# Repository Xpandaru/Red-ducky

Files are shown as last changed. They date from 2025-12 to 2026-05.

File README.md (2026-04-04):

# Red-ducky

render_2 In this project I'll make my own Rubber Ducky, named Red ducky ! A Rubber Ducky is a hacking tool that mimics a keyboard to inject a sequence of keys. I started this project with no knowledge of PCB design, so it promises to be very educational.

## The story of the project

It all started when a friend introduced me to [Hack Club](https://hackclub.com/) during the [Cyber Ninja CTF](https://www.cyber-ninja-ctf.fr/) (a cybersecurity competition organized by [Oteria Cyber School](https://www.oteria.fr/)). I was quickly drawn to the [Blueprint program](https://blueprint.hackclub.com) because I knew absolutely nothing about electronics, and being very curious, I saw it as the perfect opportunity to explore the field. I soon had the idea to recreate a Rubber Ducky (a very popular cybersecurity tool) to understand how it worked and have my own by the end of the project. From there, I began learning all the necessary knowledge and developing my project based on the [custom devboard](https://blueprint.hackclub.com/starter-projects/devboard) guided project.

## Some screenshots

rendu_1

### The PCB :



### The schematic :



# How to build

## Ordering the PCB from JLCPCB

[JLCPCB](https://jlcpcb.com/) is a company that offers fast and affordable PCB manufacturing and assembly services through an easy-to-use online platform.

First, go to the [JLCPCB](https://jlcpcb.com/) website and start a new order by clicking the “Order Now” button in the top-right corner. Then, upload the [PRODUCTION.zip](https://github.com/Xpandaru/Red-ducky/blob/main/PCB/PRODUCTION/PRODUCTION.zip) file in the “Add Gerber File” field. You don’t need to change any settings except “PCB Qty” to select how many Red-Ducky boards you want. At the very bottom, enable “PCB Assembly”; again, you don’t need to change any settings. Finally, click “Next” on the right side of the screen under “Calculated Price.” Once that’s done, click “Next” again to reach the “Bill of Materials” tab, and upload the [BOM.csv](https://github.com/Xpandaru/Red-ducky/blob/main/PCB/PRODUCTION/BOM.csv) and [CPL.csv](https://github.com/Xpandaru/Red-ducky/blob/main/PCB/PRODUCTION/CPL.csv) files available in the repository.

Then click “Process BOM & CPL”, and you will see the list of components appear. However, you will likely notice that component **J1** shows an error in the “Select” column labeled “Standard Only.” This happens because the “PCBA Type” setting is still set to “Economic.” To fix this, you have two options : either click “Standard Only” and then “Switch to Standard PCBA” (which will increase the price), or click “Next” and choose “Do not place” in each popup, which will remove the component from the assembly. If you choose the second option, you will need to purchase the part separately (for example from [LCSC](https://www.lcsc.com/product-detail/C2765195.html)) and solder it yourself.

After that, you will see a preview of the components placed on the PCB, just make sure that the placement matches the image below and you can simply click “Next” and follow the instructions to complete your assembled PCB order.
Capture d'écran 2026-04-04 154840

## Building the Red-Ducky

Once you have received all the parts, solder **J1** if you ordered it separately. Otherwise, you just need to 3D print the [case](https://github.com/Xpandaru/Red-ducky/tree/main/CAD) available in the repository (I haven’t had the chance to print it yet, so I’m not sure if it works) and place the fully assembled Red-Ducky inside !

Finally, you can simply follow the tutorials in the [wiki](https://github.com/Xpandaru/Red-ducky/wiki) to flash the firmware and start using your Red-Ducky.

# Bill of materials

| Item | Description | Quantity | Unit price (\$) | Total prince (\$) | URL |
| --- | --- | ---: | ---: | ---: | --- |
| 0402CG330J500NT | 33pF 50V C0G ±5% 0402 Multilayer Ceramic Capacitors MLCC - SMD/SMT ROHS | 4 | 0.001 | 0.004 | https://jlcpcb.com/partdetail/1914-0402CG330J500NT/C1562 |
| DSX321G 12MHz | SMD3225-4P Crystals ROHS | 5 | 0.4003 | 2.0015 | https://jlcpcb.com/partdetail/KDSDaishinku-DSX321G12MHz/C93234 |
| KT-0603W | 100mW 120° 2.6V~3.1V 360mcd 5mA Discrete Diode White Yellow Lens op View Mount 0603 LED Indication - Discrete ROHS | 2 | 0.0104 | 0.0208 | https://jlcpcb.com/partdetail/Hubei_KENTOElec-KT0603W/C2290 |
| CL05A105KA5NQNC | 1uF 25V X5R ±10% 0402 Multilayer Ceramic Capacitors MLCC - SMD/SMT ROHS | 4 | 0.0029 | 0.0116 | https://jlcpcb.com/partdetail/53938-CL05A105KA5NQNC/C52923 |
| RP2040 | 12bit 133MHz 30 LQFN-56(7x7) Microcontrollers (MCU/MPU/SOC) ROHS | 2 | 0.9298 | 1.8596 | https://jlcpcb.com/partdetail/RaspberryPi-RP2040/C2040 |
| 0402WGF1001TCE | \-55℃~+155℃ 1kΩ 50V 62.5mW Thick Film Resistor ±1% ±100ppm/℃ 0402 Chip Resistor - Surface Mount ROHS | 6 | 0.0006 | 0.0036 | https://jlcpcb.com/partdetail/12256-0402WGF1001TCE/C11702 |
| W25Q16JVUXIQ | \-40℃~+85℃ 100,000 Cycles 10uA 133MHz 16Mbit 2.7V~3.6V 20 Years 3ms SPI USON-8-EP(2x3) NOR FLASH ROHS | 2 | 0.5448 | 1.0896 | https://jlcpcb.com/partdetail/WinbondElec-W25Q16JVUXIQ/C2843335 |
| CL05B104KO5NNNC | 100nF 16V X7R ±10% 0402 Multilayer Ceramic Capacitors MLCC - SMD/SMT ROHS | 22  | 0.0012 | 0.0264 | https://jlcpcb.com/partdetail/1877-CL05B104KO5NNNC/C1525 |
| 0402WGF1002TCE | \-55℃~+155℃ 10kΩ 50V 62.5mW Thick Film Resistor ±1% ±100ppm/℃ 0402 Chip Resistor - Surface Mount ROHS | 2 | 0.0005 | 0.001 | https://jlcpcb.com/partdetail/26487-0402WGF1002TCE/C25744 |
| CL10A106KP8NNNC | 10V 10uF X5R ±10% 0603 Multilayer Ceramic Capacitors MLCC - SMD/SMT ROHS | 4 | 0.0057 | 0.0228 | https://jlcpcb.com/partdetail/20411-CL10A106KP8NNNC/C19702 |
| 0402WGF220JTCE | \-55℃~+155℃ 22Ω 50V 62.5mW Thick Film Resistor ±1% ±100ppm/℃ 0402 Chip Resistor - Surface Mount ROHS | 4 | 0.0006 | 0.0024 | https://jlcpcb.com/partdetail/25835-0402WGF220JTCE/C25092 |
| MCP1700T-3302E/TT | IC REG LINEAR 3.3V 250MA SOT23-3 | 2 | 0.51 | 1.02 | https://www.lcsc.com/product-detail/C39051.html |
| MOLEX 48037-2200 | USB-A (USB TYPE-A) Receptacle Connector 4 Position Solder Cup | 2 | 2.0539 | 4.1078 | https://www.lcsc.com/product-detail/C2765195.html |
| SKRKAHE020 | SWITCH TACTILE SPST-NO 0.05A 12V | 2 | 0.41 | 0.82 | https://www.lcsc.com/product-detail/C202388.html |
| PCB | Green, 1.6 Thickness, HASL(with lead) | 5 | 0.4 | 2 | |
| PCBA | Assemble top side | 2 | 12.875 | 25.75 | |
| 3D printing | 3D printing of the case | 1 | 0.87 | 0.87 | |

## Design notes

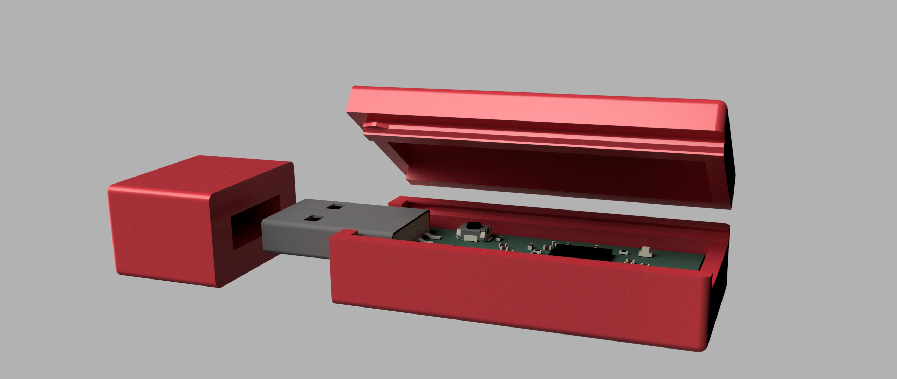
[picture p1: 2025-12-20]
CAD/render_2.png

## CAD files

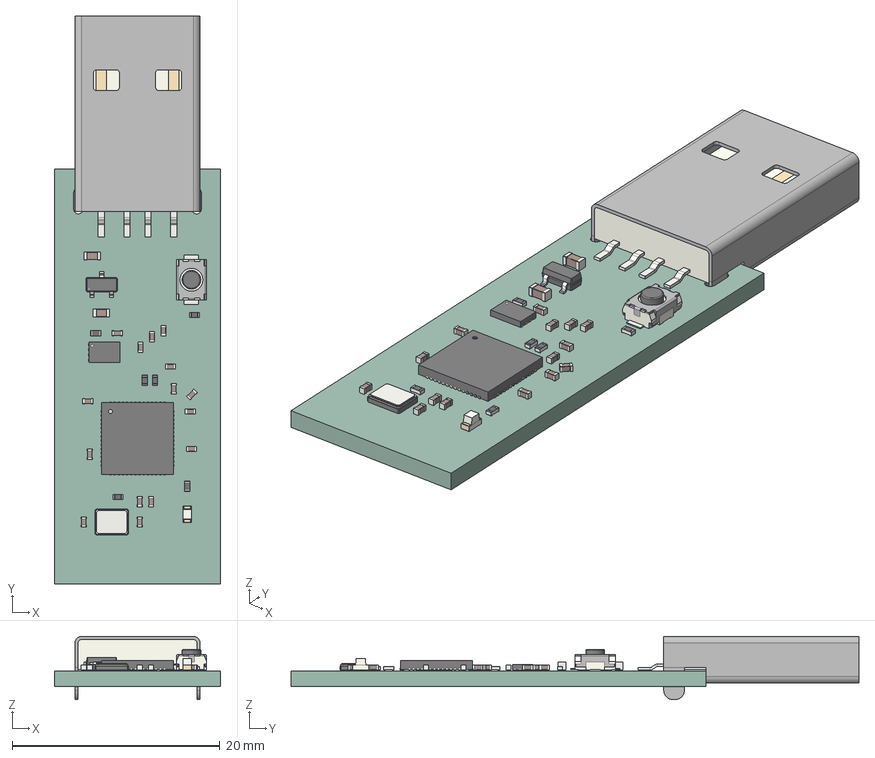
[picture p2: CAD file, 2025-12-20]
CAD/red_ducky.step
16.0 x 54.7 x 6.10 mm
R_0402_1005Metric x 6
LED_0603_1608Metric
C_0402_1005Metric x 15
C_0603_1608Metric x 2
Crystal_SMD_3225-4Pin_3.2x2.5mm
QFN-56-1EP_7x7mm_P0.4mm_EP3.2x3.2mm
USB_A_CNCTech_1001-011-01101_Horizontal
Winbond_USON-8-1EP_3x2mm_P0.5mm_EP0.2x1.6mm
SOT-23
SW_Push_SPST_NO_Alps_SKRK
custom_rubber_ducky_PCB

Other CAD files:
CAD/red_ducky-case.f3d

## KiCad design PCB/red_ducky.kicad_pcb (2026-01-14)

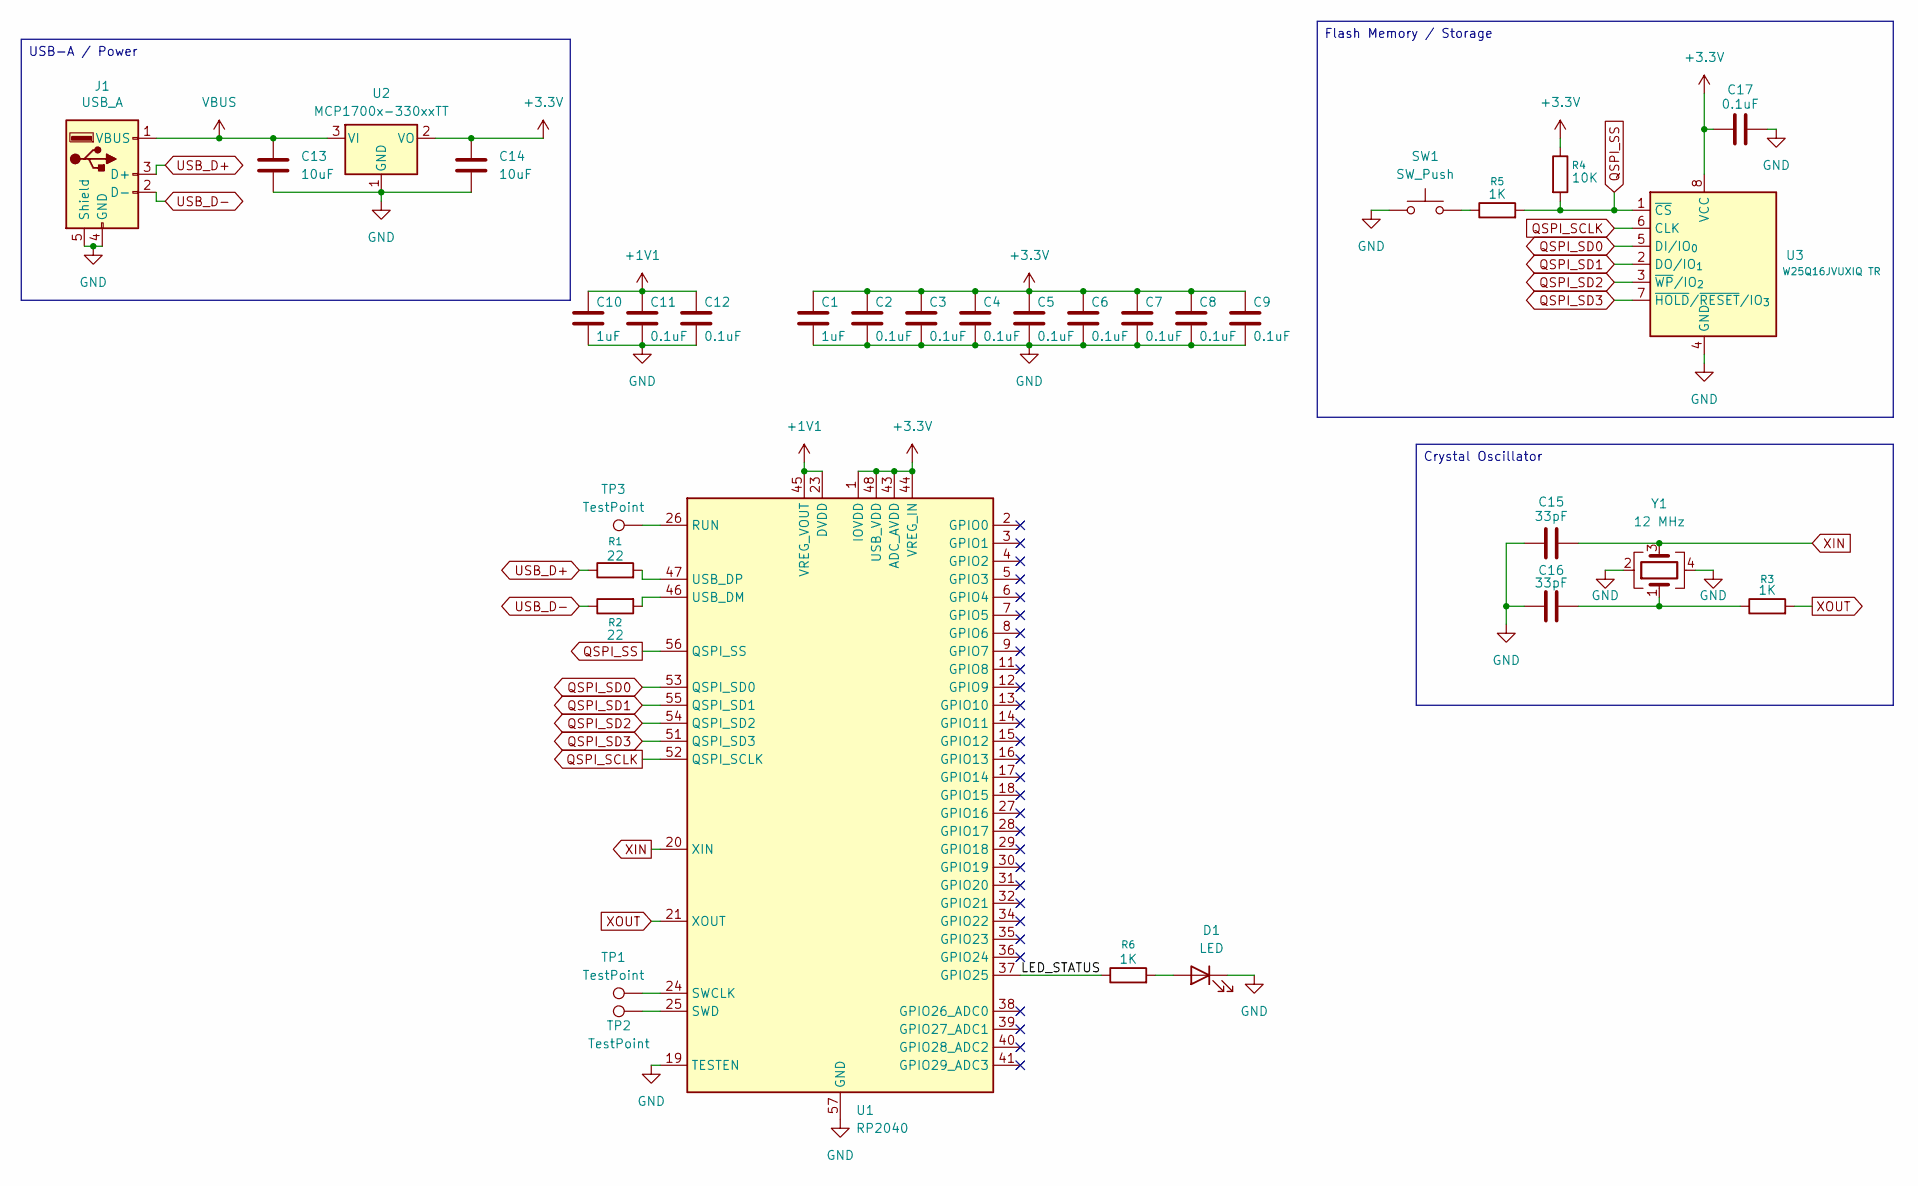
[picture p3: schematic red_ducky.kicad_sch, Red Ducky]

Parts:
C1, C10: 1uF; C_0402_1005Metric
C2, C3, C4, C5, C6, C7, C8, C9, C11, C12, C17: 0.1uF; C_0402_1005Metric
C13, C14: 10uF; C_0603_1608Metric
C15, C16: 33pF; C_0402_1005Metric
D1: LED; LED_0603_1608Metric
J1: USB_A; USB_A_CNCTech_1001-011-01101_Horizontal
R1, R2: 22; R_0402_1005Metric
R3, R5, R6: 1K; R_0402_1005Metric
R4: 10K; R_0402_1005Metric
SW1: SW_Push; SW_Push_SPST_NO_Alps_SKRK
TP1, TP2, TP3: TestPoint; TestPoint_Pad_1.5x1.5mm
U1: RP2040; QFN-56-1EP_7x7mm_P0.4mm_EP3.2x3.2mm
U2: MCP1700x-330xxTT; SOT-23
U3: W25Q16JVUXIQ TR; Winbond_USON-8-1EP_3x2mm_P0.5mm_EP0.2x1.6mm
Y1: 12 MHz; Crystal_SMD_3225-4Pin_3.2x2.5mm

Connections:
+1V1: C10.1, C11.1, C12.1, U1.23 (DVDD), U1.45 (VREG_VOUT), U1.50 (DVDD)
+3.3V: C1.1, C2.1, C3.1, C4.1, C5.1, C6.1, C7.1, C8.1, C9.1, C14.1, C17.1, R4.1, U1.1 (IOVDD), U1.10 (IOVDD), U1.22 (IOVDD), U1.33 (IOVDD), U1.42 (IOVDD), U1.43 (ADC_AVDD), U1.44 (VREG_IN), U1.48 (USB_VDD), U1.49 (IOVDD), U2.2 (VO), U3.8 (VCC)
/LED_STATUS: R6.1, U1.37 (GPIO25)
GND: C1.2, C2.2, C3.2, C4.2, C5.2, C6.2, C7.2, C8.2, C9.2, C10.2, C11.2, C12.2, C13.2, C14.2, C15.1, C16.1, C17.2, D1.1 (K), J1.4 (GND), J1.5 (Shield), SW1.1, U1.19 (TESTEN), U1.57 (GND), U2.1 (GND), U3.4 (GND), Y1.2, Y1.4
unnamed: C16.2, R3.1, Y1.1
unnamed: D1.2 (A), R6.2
unnamed: R5.1, SW1.2
unnamed: TP3.1, U1.26 (RUN)
unnamed: TP1.1, U1.24 (SWCLK)
unnamed: TP2.1, U1.25 (SWD)
unnamed: R2.2, U1.46 (USB_DM)
unnamed: R1.2, U1.47 (USB_DP)
QSPI_SCLK: U1.52 (QSPI_SCLK), U3.6 (CLK)
QSPI_SD0: U1.53 (QSPI_SD0), U3.5 (DI/IO_{0})
QSPI_SD1: U1.55 (QSPI_SD1), U3.2 (DO/IO_{1})
QSPI_SD2: U1.54 (QSPI_SD2), U3.3 (~WP/IO_{2})
QSPI_SD3: U1.51 (QSPI_SD3), U3.7 (~HOLD/~RESET/IO_{3})
QSPI_SS: R4.2, R5.2, U1.56 (QSPI_SS), U3.1 (~CS)
USB_D+: J1.3 (D+), R1.1
USB_D-: J1.2 (D-), R2.1
VBUS: C13.1, J1.1 (VBUS), U2.3 (VI)
XIN: C15.2, U1.20 (XIN), Y1.3
XOUT: R3.2, U1.21 (XOUT)

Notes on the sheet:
Crystal Oscillator
Flash Memory / Storage
USB-A / Power

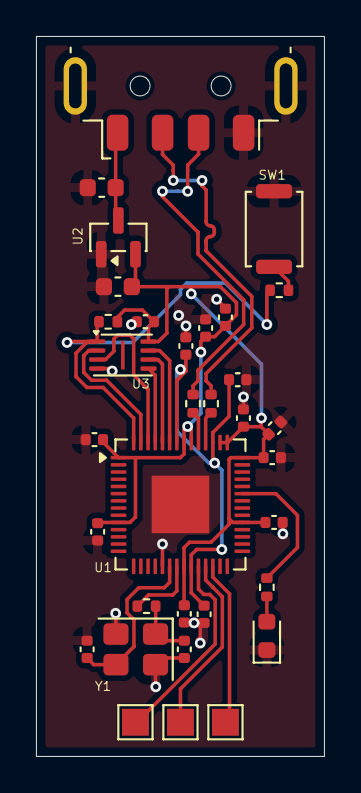
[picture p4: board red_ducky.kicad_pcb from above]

Board: 2 copper layers, 16.0 x 40.0 mm, 33 parts (0 on the bottom side), 23 nets.

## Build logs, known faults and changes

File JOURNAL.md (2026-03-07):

# Journal
### Total time spent : 49 hours
All entries below are a transcription of the journal on the [blueprint program platform](https://blueprint.hackclub.com/projects/5896) because I created the github page afterwards.

## Day 1 (12/10/2025, session of 2 hours) : Preparation and schematic start
There we go !
With the help of the Custom Devboard tutorial, I succeed to make the base of my project by placing the first components in the schematic.
For now there is just this two components :
- RP2040
- USB-A

It doesn't look like much at the moment, but I'm going to improve it for the future.



## Day 2 (12/11/2025, session of 2 hours) : Finished the schematic !
So today, I've finally finished the schematic ! I don't really know if all is correct but I'm counting on you to tell me if I made something bad.
Still with the help of the Custom Devboard tutorial, I successfully set up all the components needed in my project :
- RP2040
- USB-A
- 3.3V LDO
- Quad SPI flash memory
- 12 MHz crystal oscillator

Here's the result :



## Day 3 (12/12/2025, session of 1.7 hours) : Assigning footprints and starting the board
Today I've finished to assign footprints to each component, so here's the result :



After I started to organise all of the components on the board and wiring some of them. But I'm still far from finished. Here's a screenshot showing where I'm at :



## Day 4 (12/16/2025, session of 2 hours) : Routing
During this session, I continued routing all my components. It took me a long time because I had particular difficulty to cross the two D- and D+ routes, I thought I shouldn't use vias. Finally, after a few complications, here's the result :



## Day 4, 2nd entry (12/16/2025, session of 1.3 hours) : Finishing PCB
I've finally finished the PCB ! I've completed the routing and fixed the errors flagged by the DRC. I've tweaked a few details here and there, so I've included the schematic, PCB layout, and 3D rendering below.





## Day 5 (12/17/2025, session of 2 hours) : Designing the box
Today I started 3D modeling the box that will house my PCB. I chose to use Fusion 360 software for this. I haven't made the lid yet, but here's what it looks like :



I opted for a sliding cover to make it easier to open and provide easy access to the circuit board. Here's a zoomed-in image of the mounting system.



## Day 5, 2nd entry (12/17/2025, session of 0.2 hours) : Patched PCB
I noticed I had placed vias directly on the solder pads, which is not recommended. So I corrected everything by offsetting the vias each time. Here's a screenshot of the patched PCB.



## Day 5, 3rd entry (12/17/2025, session of 1.5 hours) : Continuation of the box design
I continued designing the box, making a few improvements. First, I changed the mounting system by adding a ramp on each side of the pinion to prevent it from jamming. Next, I made the top part of the box. Finally, to soften the shape, I rounded the edges. Next time, I'll make the cap for the USB port. Here's what the box looks like :




## Day 6 (12/20/2025, session of 1 hour) : Finishing the box
Today I've finaly finished the box design ! I added a cap for the USB and a little hole filled with a transparent texture for the LED. To finish I changed the color to red because it looks better than in white ! Here are two screenshots of the result :




## Day 7 (12/21/2025, session of 2.5 hours) : Creation of the GitHub repository
I finally created the project's GitHub page by following the submission guidelines step by step. I had a lot of trouble choosing the components on JLCPCB because I was completely lost; some components on Kicad didn't exist on JLCPCB, so I had to choose equivalents, but it was complicated to know which ones to select. Well, after two and a half hours of struggling, I finally succeeded, so I'm quite happy to have completed this step. All that's left is to create the firmware to validate the project.

## Day 8 (12/22/2025, session of 1 hour) : Creating the firmware
To finalize the design, I created the firmware. Since I don't know the C programming language and the project needs to be completed before January 1st, I had the firmware generated by AI. I still understand the main coded actions, though, because I like to know how things work. To create the firmware, I used the Pico SDK, which I referenced in Dependencies.txt.

## Day 9 (02/24/2026, session of 4 hours) : Soldering parts
After finally receiving all the necessary parts, I was finally able to start soldering. I had never soldered onto a PCB before. So I started by soldering the parts of my macropad to practice, and it wasn't easy! After hours of struggling, I finally managed to solder everything. And I had the wonderful news that my computer recognized a new device, a sign that everything is working correctly. So I've finally finished the physical part and I'm going to start working on the firmware. Below is a photo of the fully soldered Red Ducky :



## Day 10 (02/25/2026, session of 2.5 hours) : Making my first firmware !
After finishing the physical part of the project, I had to start working on the firmware. While researching, I learned that it have to be coded in C, but I had never coded in C before ! So I used an AI that taught me the basics to create a first "blink" firmware that simply makes the LED blink. Again, I encountered many problems that ultimately led me to use WSL to finally compile the firmware. So here's a picture of my first working firmware :



## Day 11 (02/26/2026, session of 3 hours) : Finally Recognized by Windows !
After creating my first "blink" firmware, I started improving it so my Red Ducky would be recognized as a device by the computer by using TinyUSB. Again, after encountering tons of bugs, I managed to get it working. For now, it only lights up an LED and is recognized by Windows, but that's already a small victory for me. The next step will be to make it work as a keyboard-like device (fingers crossed I don't run into any bugs). Here's a screenshot of the device recognized by Windows :

Capture d'écran 2026-02-26 155719

## Day 12 (02/27/2026, session of 3 hours) : First keys typings
To continue working on the firmware, I again asked an AI agent for help. This allowed me to first get my Red Ducky recognized as an HID device (keyboard). Then I implemented a system for typing keys. I managed to get it to type "Hello World" when plugged in.

The next step was to create a mini-language like "STRING Hello World" that would allow me to change the payload without modifying the firmware. I finally got it working after many problems and implemented the STRING, DELAY, ENTER, and KEYCOMBO commands. But while trying to fix an error caused by the KEYCOMBO commands, I realized I had overused vibe coding and no longer understood my own code.

Since I'm stuck, I'm going to go back a bit, but this time without vibe coding, to fully understand what I'm doing. We'll see how it goes in the next journal entry.

## Day 12, 2nd entry (02/27/2026, session of 2.5 hours) : New start without vibe coding
For this new firmware version, which I'm coding myself, I've recreated a function that allows the Red Ducky to type a string, currently accepting only lowercase and uppercase letters, numbers, and certain characters like ".", "!", and spaces. I then put the function that converts the characters to HID code in a separate file for better organization. I've also added a parameter to this function that allows you to convert the keys to either AZERTY or QWERTY layout. And I'm quite proud of the result !



## Day 13 (02/28/2026, session of 2.8 hours) : Making my own script language
To improve the firmware, I had the idea of creating my own version of DuckyScript. This will allow me to avoid recompiling the firmware later, but since my C skills are very limited, I had a lot of trouble setting this up. So I started by coding a parser, which will be the basis of the language. I first implemented the STRING command, which simply allows you to type the following text. And after many struggles, I managed to retype "Hello World!" using the parser. For now, the script is stored in a simple array within the firmware, but I will later implement a system to read a script from a separate file. I then added the DELAY command (waits the specified number of milliseconds) and ENTER (presses Enter). Below is a screenshot of a small example DuckyScript :



## Day 13, 2nd entry (02/28/2026, session of 3 hours) : Improved DuckyScript and list of supported characters
Since my last journal entry, the firmware has changed a lot. I started by adding two features to my parser (DuckyScript) that now allow me to type key combinations (like CTRL+C) or special keys (like TAB). I encountered many problems again, especially when coding the parser function that read the key combinations. I then added many useful keyboard keys, which also took a lot of time. The most time-consuming part was completely redesigning the AZERTY layout so that Red Ducky works equally well in both AZERTY and QWERTY.
I'll update the firmware on the repository so you can see it in more detail.

## Day 14 (03/05/2026, session of 2.8 hours) : Patching and upgrading the firmware
To begin, I fixed some major firmware bugs :
- The first was that the `DELAY` command no longer worked. Upon investigation, I noticed that it was being overridden by the `global_delay` variable, which creates a delay between each script command. I then implemented conditions that would give `DELAY` priority over `global_delay`.
- The second bug was that special keys would remain pressed indefinitely. I investigated and found that this was due to the `hid_type_task()` function returning because there was no text to type. I then added an exception for special keys so that the function would still execute.

I then added several new commands :

- `LAYOUT`, which takes `AZERTY` or `QWERTY` as an argument, allows you to change the keyboard layout directly in the script.
- `REM` ignores everything written after it on the line, this allows for comments in the script.
- `REPEAT`, which takes an integer as an argument, allows you to repeat the following command the specified number of times.
- `STRINGLN` behaves like `STRING` but always presses enter after the text.

Finally, I increased the maximum size of a `STRING` to 1000 characters.

## Day 15 (03/06/2026, session of 3.8 hours) : Adding a serial monitor support
After fully completing the core of the firmware, I needed to start creating an interface between the Red Ducky and the computer so I could debug errors and, more importantly, modify the script without having to change and recompile the firmware. I enabled CDC alongside HID so the Red Ducky would be recognized by the serial monitor while still being detected as a keyboard at the same time. This part was tricky because I’m not very comfortable with USB configurations. Still, I managed to write my first “hello world” in the serial monitor.

Then, after coding the foundation of an input‑reading system, I created the commands `EDIT START` and `EDIT QUIT`, which allow entering a special mode to modify the script. I also added the commands `SCRIPT BEGIN`, `SCRIPT END`, and `SCRIPT SHOW`. The first two let you write a new script between them, and `SCRIPT SHOW` returns the current script.

At that point, I realized I had already been working for 3 hours and 45 minutes, so I’m taking a break to add a journal entry. There should be plenty of new things in the next journal entry.

## Day 16 (03/07/2026, session of 2.5 hours) : Finishing the firmware
As promised, this new journal entry comes with plenty of new features !
First of all, I’ve added new commands to the serial monitor :

- `SCRIPT EDIT` lets you modify the current script. It’s an alternative to `SCRIPT BEGIN` so you don’t have to start over from scratch.

- `SCRIPT DEL` allows you to delete the last line of the script while editing or writing it, in case you made a mistake.

Next, I completely overhauled the firmware so that the script is stored in the flash memory and loaded every time the device is plugged in. Thanks to this, any script modifications made through the serial monitor are now persistent.

So I’m happy to announce that the Red Ducky firmware is officially finished, and everything seems to be working properly.

The final step will be to write a small wiki to explain each command in detail.

## Day 16, 2nd entry (03/07/2026, session of 1.9 hours) : Making the wiki
To finish this project, I decided to create a complete wiki documenting all the commands and ways to use the Red Ducky. I also slightly modified the firmware so that it writes errors to the serial monitor. If you're interested here's the link to the [wiki](https://github.com/Xpandaru/Red-ducky/wiki).

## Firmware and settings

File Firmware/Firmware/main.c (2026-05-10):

#include <stdio.h>
#include "pico/stdlib.h"
#include "bsp/board.h"
#include "tusb.h"
#include "layout.h"
#include "parser.h"
#include "cdc_input.h"
#include "script_storage.h"

#define MAX_SCRIPT_LINES 200

typedef enum {
    TYPE_IDLE,
    TYPE_PRESS,
    TYPE_RELEASE
} type_state_t;

typedef enum {
    MODE_ACTIVE,
    MODE_EDIT,
    MODE_WRITING,
    MODE_ERROR
} SystemMode;

// Variables declaration

static SystemMode system_mode = MODE_ACTIVE;
static char cdc_line_buffer[1009];
static int cdc_error = 0;
static int show_line_count = 0;
static int write_line_count = 0;

static int script_length = 0;
static bool script_done = false;

static int global_delay = 0;

static type_state_t type_state = TYPE_IDLE;
static const char* current_text = NULL;
static int current_index = 0;
static bool typing_done = true;

static bool is_forced = false;
static uint8_t forced_keycode = 0;
static uint8_t forced_modifier = 0;

static  int repeat = 0;

static absolute_time_t next_event_time;
static absolute_time_t delay_until;

// Functions declaration

void hid_press(uint8_t keycode, uint8_t modifier) {
    uint8_t keys[6] = {0};
    keys[0] = keycode;
    tud_hid_keyboard_report(0, modifier, keys);
}

void hid_release(void) {
    uint8_t empty[6] = {0};
    tud_hid_keyboard_report(0, 0, empty);
}

void start_typing(const char* text) {
    current_text = text;
    current_index = 0;
    type_state = TYPE_IDLE;
    typing_done = false;
    next_event_time = get_absolute_time();
}

void hid_type_task(void) {
    if (!tud_hid_ready()) return;
    if (typing_done) return;
    if (!time_reached(next_event_time)) return;

    static uint8_t modifier = 0;
    static uint8_t keycode = 0;

    if (!is_forced) {

        char c = current_text[current_index];

        if (c == '\0') {
            typing_done = true;
            type_state = TYPE_IDLE;
            return;
        }

        modifier = 0;
        keycode = layout_get_keycode(c, &modifier);

    }
    else {
        modifier = forced_modifier;
        keycode = forced_keycode;
    }

    // States

    switch (type_state) {
        case TYPE_IDLE:
            hid_press(keycode, modifier);
            type_state = TYPE_PRESS;
            next_event_time = make_timeout_time_ms(1);
            break;

        case TYPE_PRESS:
            hid_release();
            type_state = TYPE_RELEASE;
            next_event_time = make_timeout_time_ms(2);
            break;

        case TYPE_RELEASE:
            if (is_forced) {
                is_forced = false;
                typing_done = true;
            }
            else {
                current_index++;
            }
            type_state = TYPE_IDLE;
            next_event_time = make_timeout_time_ms(2);
            break;
    }
}

void execute_command(Command* cmd) {
    switch (cmd->type) {

        case CMD_REM:
            break;

        case CMD_LAYOUT:
            if (strcmp(cmd->argument, "AZERTY") == 0) is_azerty = true;
            if (strcmp(cmd->argument, "QWERTY") == 0) is_azerty = false;
            break;

        case CMD_REPEAT:
            repeat = cmd->value;
            break;
        
        case CMD_STRING:
            start_typing(cmd->argument);
            break;

        case CMD_DELAY:
            delay_until = make_timeout_time_ms(cmd->value);
            break;

        case CMD_GBDELAY:
            global_delay = cmd->value;
            break;

        case CMD_MODIFIER:
            if (cmd->keycode != 0) {
                forced_keycode = cmd->keycode;
                forced_modifier = cmd->modifier;
                is_forced = true;
                typing_done = false;
            }
            else printf("ERROR(5): Argument not found : %s - %s\n\n", cmd->modifier, cmd->keycode);
            break;

        case CMD_KEY:
            if (cmd->keycode != 0) {
                forced_keycode = cmd->keycode;
                forced_modifier = 0;
                is_forced = true;
                typing_done = false;
            }
            break;

        default:
            system_mode = MODE_ERROR;
            printf("ERROR(4): Command not found or wrong argument type : %s\n\n", cmd->argument);
            break;
    }
}

int main() {
    stdio_init_all();
    board_init();
    tusb_init();

    // LED variables

    const uint LED_PIN = 25;

    gpio_init(LED_PIN);
    gpio_set_dir(LED_PIN, GPIO_OUT);
    absolute_time_t blink_delay = get_absolute_time();
    bool led_state = false;

    absolute_time_t usb_timeout = make_timeout_time_ms(3000);
    while (!tud_hid_ready() && !time_reached(usb_timeout)) {
        tud_task();
    }

    static char* script[MAX_SCRIPT_LINES];

    if (script_is_present()) {
        script_length = script_load(script, MAX_SCRIPT_LINES);
    }
    else system_mode = MODE_EDIT;
    
    int current_line = 0;

    Command cmd;
    delay_until = get_absolute_time();

    while (true) {
        tud_task();
        hid_type_task();

        switch (system_mode) {

        case MODE_ACTIVE:
            gpio_put(LED_PIN, !script_done);
            led_state = !script_done;
            break;
        
        case MODE_EDIT:
        case MODE_WRITING:
            if (time_reached(blink_delay)) {
                led_state = !led_state;
                gpio_put(LED_PIN, led_state);
                blink_delay = make_timeout_time_ms(500);
            }
            break;

        case MODE_ERROR:
            if (time_reached(blink_delay)) {
                led_state = !led_state;
                gpio_put(LED_PIN, led_state);
                if (led_state) blink_delay = make_timeout_time_ms(100);
                else blink_delay = make_timeout_time_ms(200);
            }
            break;
        
        default:
            break;
        }

        if (tud_cdc_available()) {
            
            if (cdc_read_line(cdc_line_buffer, sizeof(cdc_line_buffer), &cdc_error)) {

                if (cdc_error == 1) {
                    printf("ERROR(1): Buffer overflow : Your last entry exceeded the supported character limit.\n\n");
                }

                if (cdc_error == 2) {
                    printf("ERROR(2): Buffer overflow : Your last entry exceeded the supported character limit.\n\n");
                }

                if (strcmp(cdc_line_buffer, "EDIT START") == 0) {

                    printf("----------{EDIT MODE ENABLED}----------"
                        "\nTo quit this mode, type : EDIT QUIT"
                        "\n\nCommands :"
                        "\n- SCRIPT EDIT : start editing the current script"
                        "\n- SCRIPT BEGIN : remove the current script to create a new script, all commands after it are saved as the new script until SCRIPT END."
                        "\n- SCRIPT END : marks the end of a script block and save it as the new script."
                        "\n- SCRIPT DEL : delete the last line of the script."
                        "\n- SCRIPT SHOW : show the current saved script."
                        "\n\n"
                    );
                    system_mode = MODE_EDIT;
                }

                if (strcmp(cdc_line_buffer, "EDIT QUIT") == 0 && system_mode != MODE_WRITING) {

                    printf("---------{EDIT MODE DISABLED}----------\n\n");
                    system_mode = MODE_ACTIVE;
                }

                if (strcmp(cdc_line_buffer, "EDIT QUIT") == 0 && system_mode == MODE_WRITING) {
                    printf("You cannot quit the EDIT MODE while editing the script. To quit the EDIT MODE, first type SCRIPT END.\n\n");
                }

                if (system_mode == MODE_EDIT) {

                    if (strcmp(cdc_line_buffer, "SCRIPT BEGIN") == 0) {
                        printf("Each new entry will be treated as a new line of the script. To exit this mode, type SCRIPT END.\n\n");
                        script[0] = NULL;
                        write_line_count = 0;
                        system_mode = MODE_WRITING;
                    }

                    if (strcmp(cdc_line_buffer, "SCRIPT EDIT") == 0) {

                        printf("---------------{SCRIPT}----------------\n");
                        show_line_count = 0;
                        while (script[show_line_count] != NULL) {
                            printf("%s\n", script[show_line_count++]);
                        }
                        printf("\nType SCRIPT END to save the script.\n\n");

                        write_line_count = script_length;
                        system_mode = MODE_WRITING;
                    }

                    else if (strcmp(cdc_line_buffer, "SCRIPT END") == 0) {
                        printf("You cannot finish a script that has not started. To start a script, type SCRIPT BEGIN.\n\n");
                    }

                    else if (strcmp(cdc_line_buffer, "SCRIPT DEL") == 0) {
                        printf("This command is only accessible when editing or writing a script. To start editing a script, type SCRIPT EDIT, or to start a script, type SCRIPT EDIT.\n\n");
                    }

                    else if (strcmp(cdc_line_buffer, "SCRIPT SHOW") == 0) {
                        printf("---------------{SCRIPT}----------------\n");

                        show_line_count = 0;
                        while (script[show_line_count] != NULL) {
                            printf("%s\n", script[show_line_count++]);
                        }
                        printf("\n");
                    }
                }
                else if (system_mode == MODE_WRITING) {

                    if (strcmp(cdc_line_buffer, "SCRIPT END") == 0) {
                        if (script_save(script)) printf("Script saved successfully !\n\n");
                        else printf("ERROR(3): Flash overflow : The script size exceeds the allocated space in the flash memory.\n\n");
                        system_mode = MODE_EDIT;
                    }

                    else if (strcmp(cdc_line_buffer, "SCRIPT DEL") == 0) {
                        write_line_count--;
                        script[write_line_count] = NULL;

                        printf("---------------{SCRIPT}----------------\n");
                        show_line_count = 0;
                        while (script[show_line_count] != NULL) {
                            printf("%s\n", script[show_line_count++]);
                        }
                        printf("\nType SCRIPT END to save the script.\n\n");
                    }

                    else {
                        script[write_line_count++] = strdup(cdc_line_buffer);
                        script[write_line_count] = NULL;

                        printf("---------------{SCRIPT}----------------\n");
                        show_line_count = 0;
                        while (script[show_line_count] != NULL) {
                            printf("%s\n", script[show_line_count++]);
                        }
                        printf("\nType SCRIPT END to save the script.\n\n");
                        
                    }
                }
            }
        }

        if ((script[current_line] == NULL && typing_done) || system_mode != MODE_ACTIVE) script_done = true;

        if (typing_done && time_reached(delay_until) && script[current_line] != NULL && !script_done) {
            
            cmd = parse_line(script[current_line]);
            execute_command(&cmd);

            if (cmd.type != CMD_DELAY 
                && cmd.type != CMD_REPEAT 
                && cmd.type != CMD_REM 
                && cmd.type != CMD_GBDELAY 
                && cmd.type != CMD_LAYOUT) delay_until = make_timeout_time_ms(global_delay);

            if (repeat <= 0 || cmd.type == CMD_REPEAT) {
                current_line++;
            }

            if (repeat > 0) repeat--;
            
        }
    }
}

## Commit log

2025-12-20 Expand README with project details and materials
    Added detailed project description, story, screenshots, and bill of materials.
2025-12-20 Add journal entries for PCB project progress
    Added a detailed journal documenting the progress of the project.
2025-12-20 Adding .step file
    [red_ducky.step]
2025-12-20 Adding the case 3D model
    [red_ducky-case.f3d]
2025-12-20 Adding Kicad files
    [red_ducky.kicad_pcb, red_ducky.kicad_sch]
2025-12-20 Adding zipped gerbers
2025-12-20 Adding PCB 3D model
    [custom_rubber_ducky.3mf]
2025-12-20 Adding the PCB 3D model
2025-12-21 Revise bill of materials format and details
    Updated the bill of materials
2025-12-21 Adding the BOM
    [BOM.csv]
2025-12-26 Updated BOM
    [BOM.csv]
2026-01-14 Update USB connector details in README
2026-01-14 Add updated kicad files
    [red_ducky.kicad_pcb, red_ducky.kicad_sch]
2026-04-04 Adding production files
    [BOM.csv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]
2026-04-04 Updating CPL.csv
    [CPL.csv]
